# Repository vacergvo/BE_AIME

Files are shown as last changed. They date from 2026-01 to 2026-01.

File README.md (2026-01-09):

# Smart Device Project: Nanoparticle Gas Sensor & IoT Shield
**UF "Smart Devices" – PTP Innovative Smart System (ISS)**

## 1. Project Overview
This project is part of the **5ISS program at INSA Toulouse**. It focuses on the development of a **nanoparticle-based gas sensing system**, designed and characterized at **AIME**, the INSA Toulouse laboratory.

The project covers the full development cycle, from sensor fabrication to data visualization. A custom **PCB** was designed, and **ESP32 firmware** was developed to exploit the gas sensor measurements and transmit the data wirelessly. The collected data is then processed and displayed on a **web-based interface**.

The system relies on **LoRa communication** for long-range data transmission and integrates both hardware and software components.

The development chain consists of :

- Hardware design (analog signal amplified through a 2-stage transimpedance amplifier tested with LTSpice and PCB design with Kicad),

- Embedded software development using Arduino,

- LoRa wireless communication,

- Data processing and visualization using Node-RED,

- Mobile application development using MIT App Inventor.

## 2. The Measurement Chain
### Nanoparticle Gas Sensor (AIME)
Developed during a training period at AIME, this sensor utilizes:
* **Synthesis**: Nanoparticles produced and deposited by dielectrophoresis.
* **Active Zone**: A sensitive layer of $WO_3$ nanoparticles integrated on aluminum interdigitated combs.
* **Target Gases**: High sensitivity to Ethanol and Ammonium.
* **Control**: Features an internal poly-silicon heating resistor and an aluminum temperature sensor.

### Analog Interface Circuit
The sensor is interfaced via a transimpedance circuit designed to measure its resistance.
* **Amplification**: Utilizes an LTC1050 precision chopper amplifier.
* **Filtering**: A low-pass filter is implemented to extract useful signals before the ADC stage.
* **Simulation**: The circuit was validated using LTSpice IV.
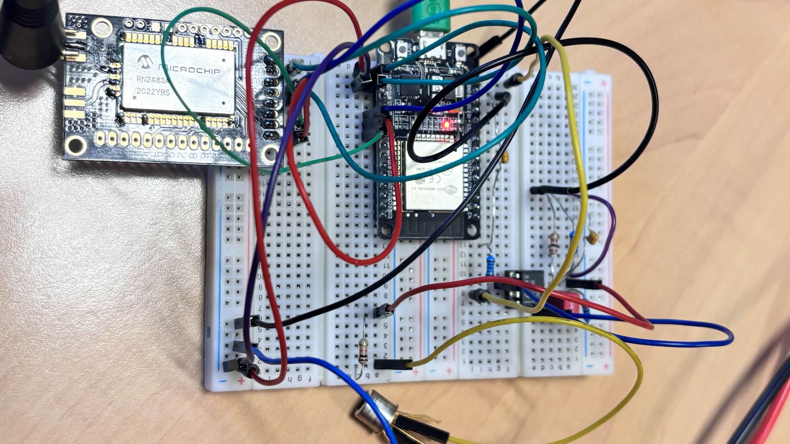
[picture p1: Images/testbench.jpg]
Hardware test

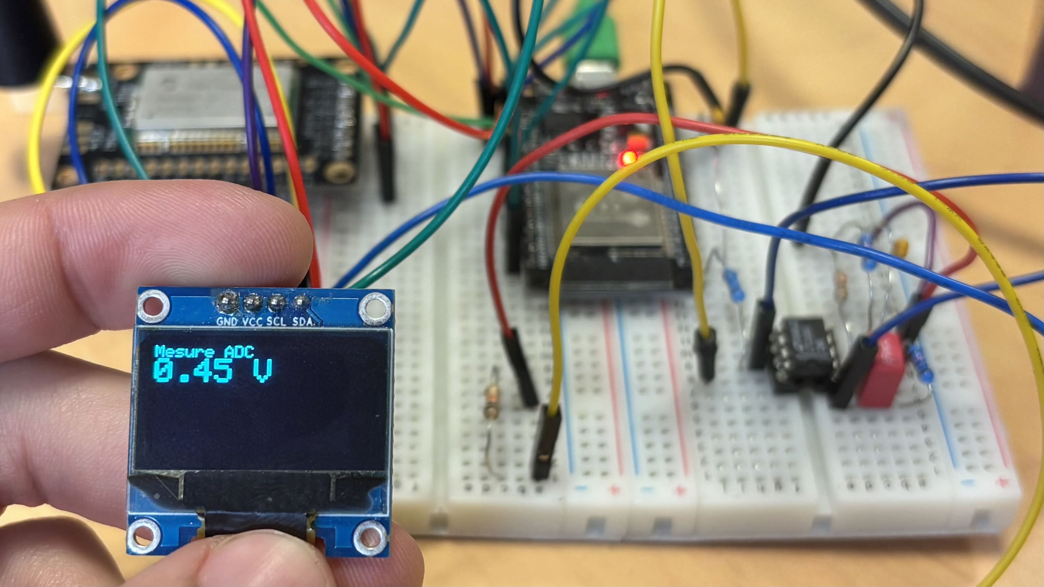
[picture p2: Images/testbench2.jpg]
Hardware test

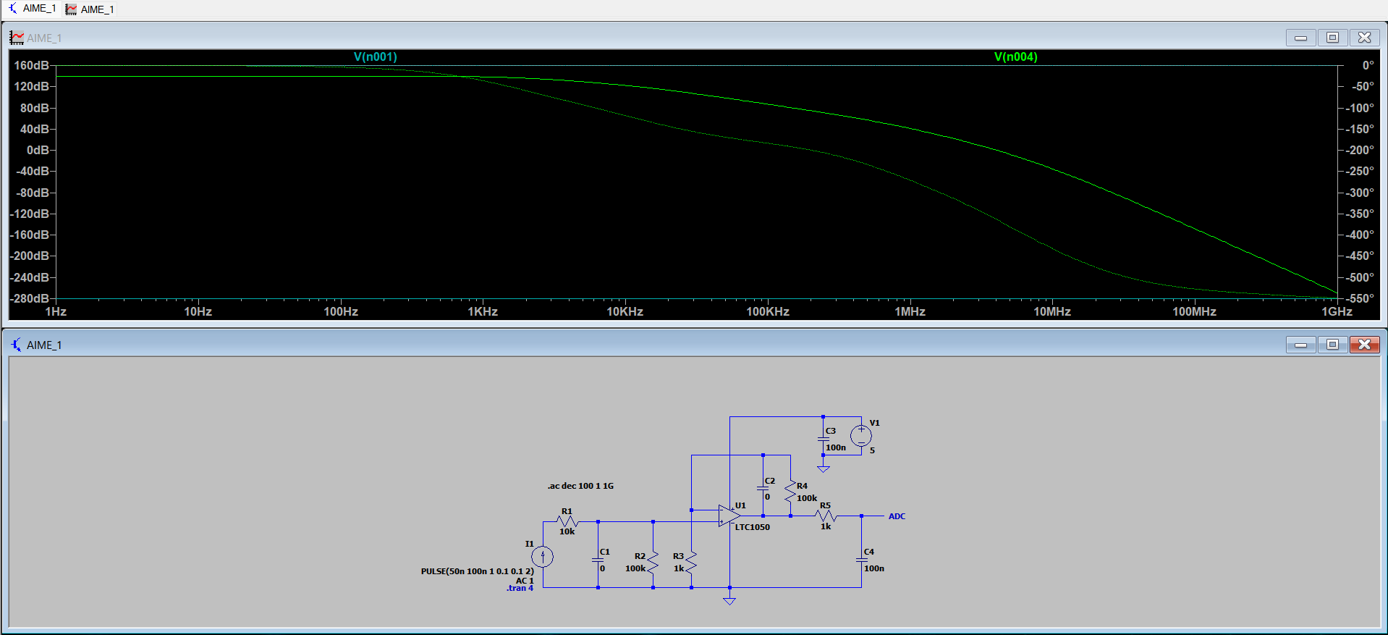
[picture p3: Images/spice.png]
LTSpice Simulation


---

## 3. Hardware Design (KiCad)
The PCB shield was designed following specific technical constraints to ensure compatibility with an Arduino UNO.

### Design Constraints:
* **Track Width**: 0.5 mm minimum.
* **Track Isolation**: 0.5 mm minimum.
* **Drill Sizes**: 1mm for headers/connectors; 0.8mm for passive components.

### Schematic & Routing
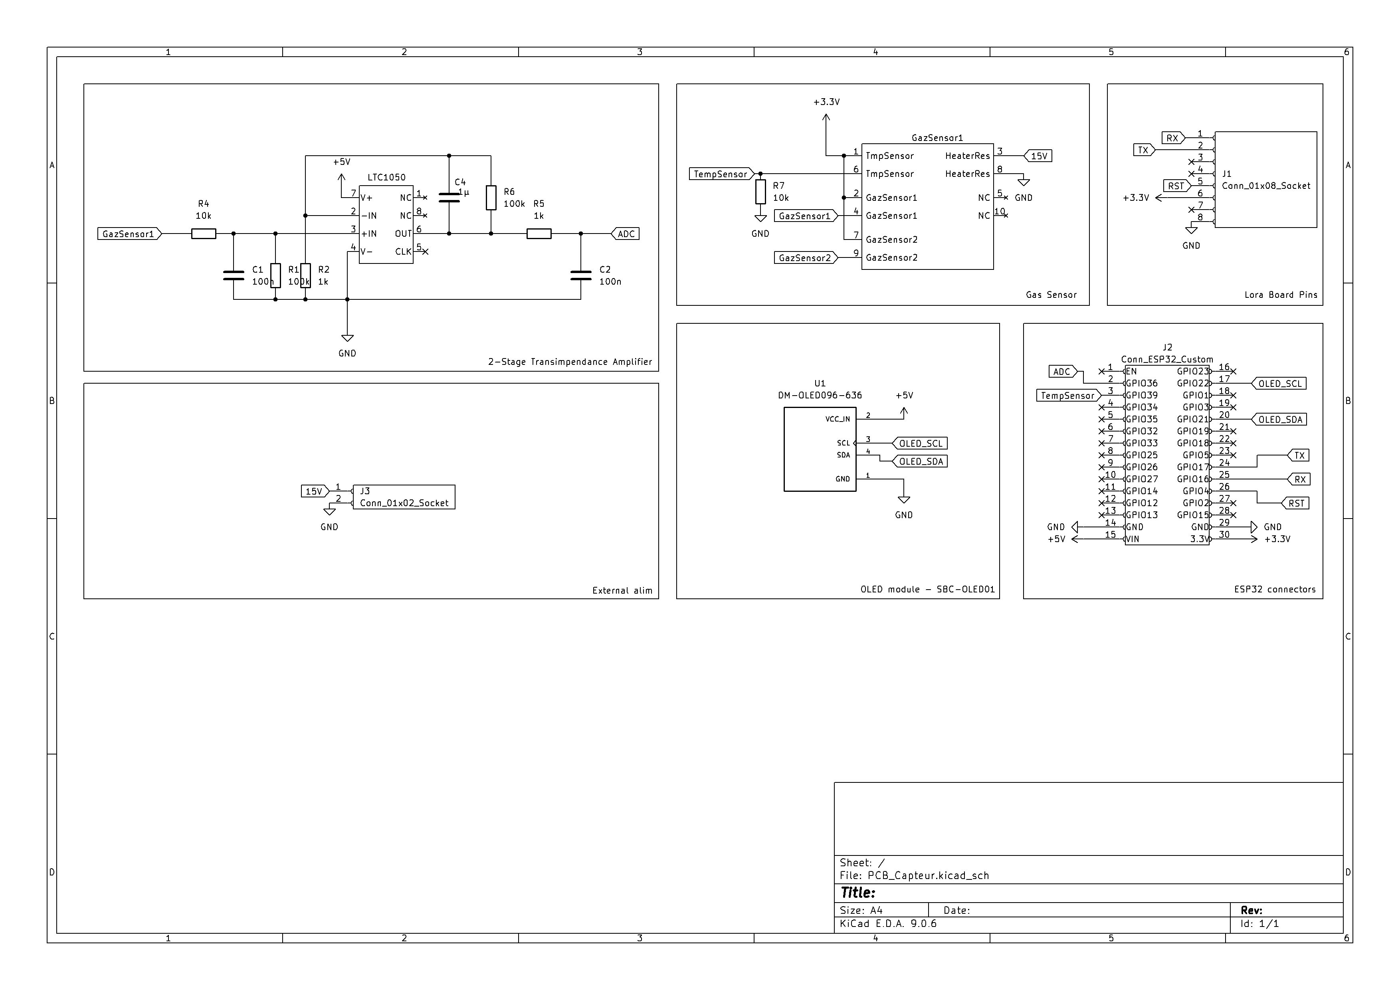
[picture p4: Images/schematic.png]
Schematic

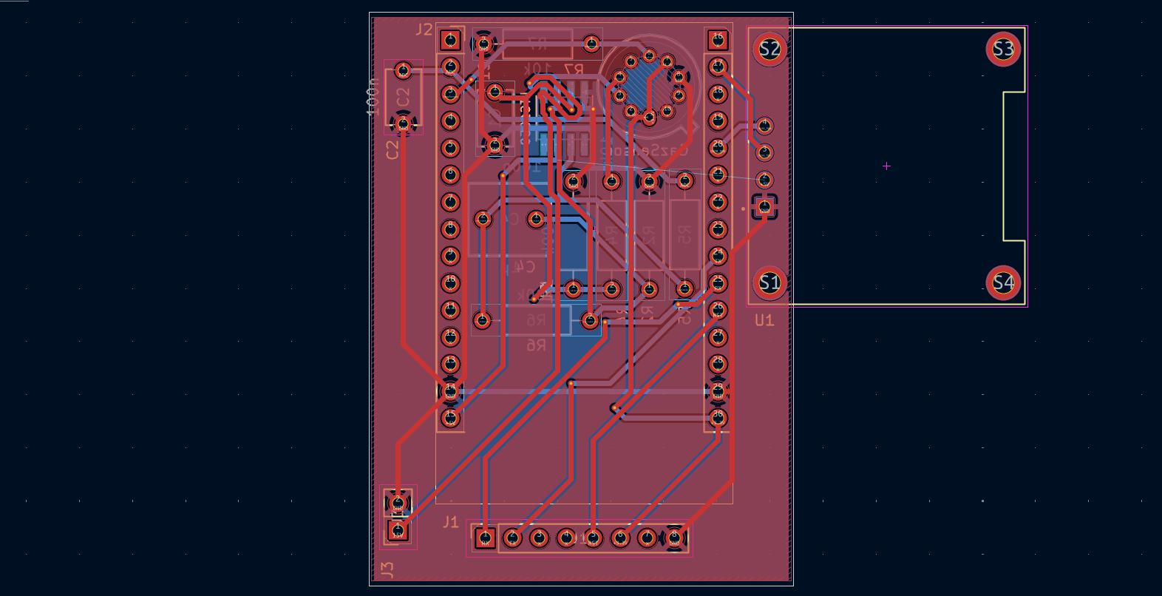
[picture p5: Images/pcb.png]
PCB Layout


### 3D Model
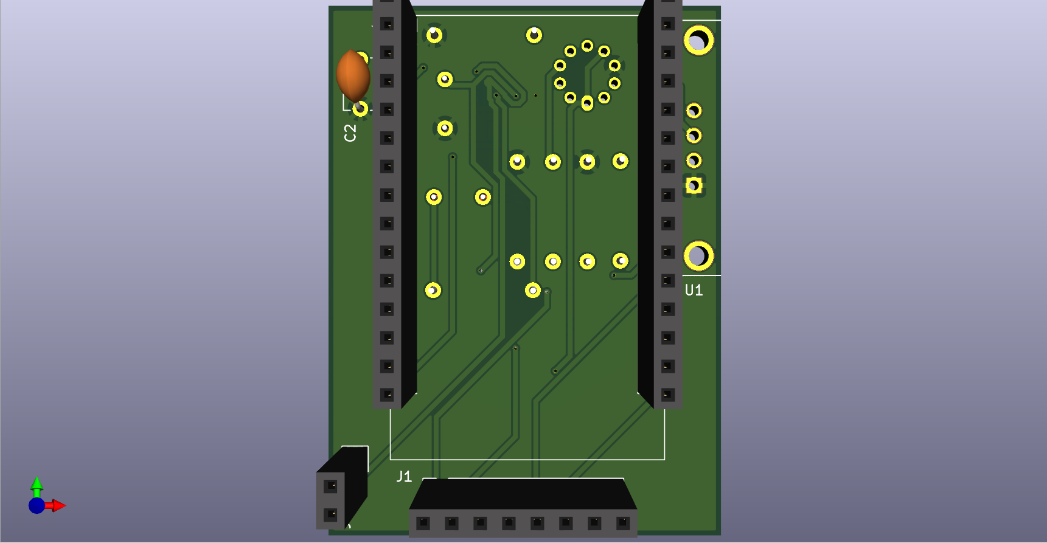
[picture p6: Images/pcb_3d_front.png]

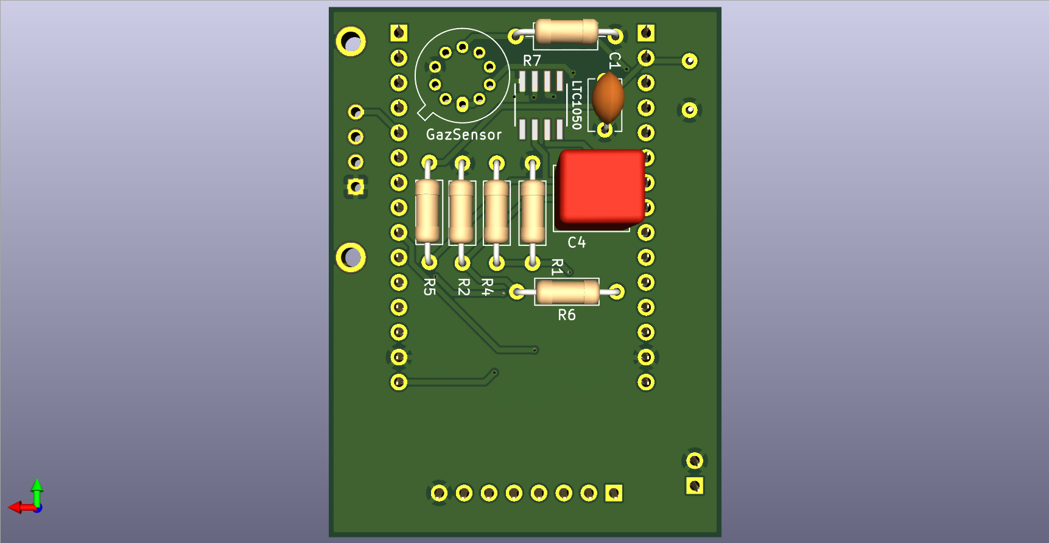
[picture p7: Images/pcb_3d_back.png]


---

## 4. Implementation & Software
* **Microcontroller**: Programmed for Arduino UNO / ESP32 platforms.
* **Connectivity**: Configured to send data over the The Things Network (TTN) via LoRa.
* **Version Control**: Developed collaboratively using Git and GitHub.
* **Interface**: NodeRed Application.

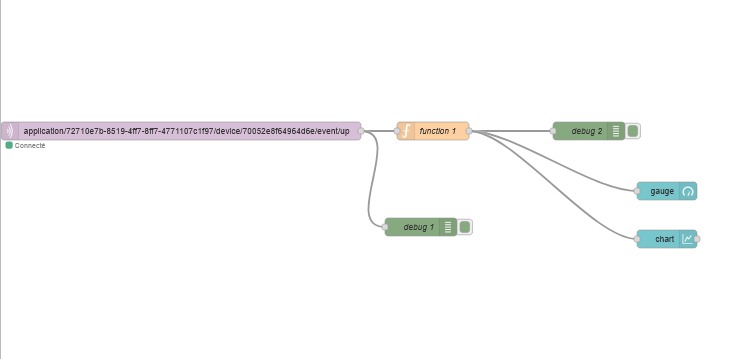
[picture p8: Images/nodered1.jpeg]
NodeRed

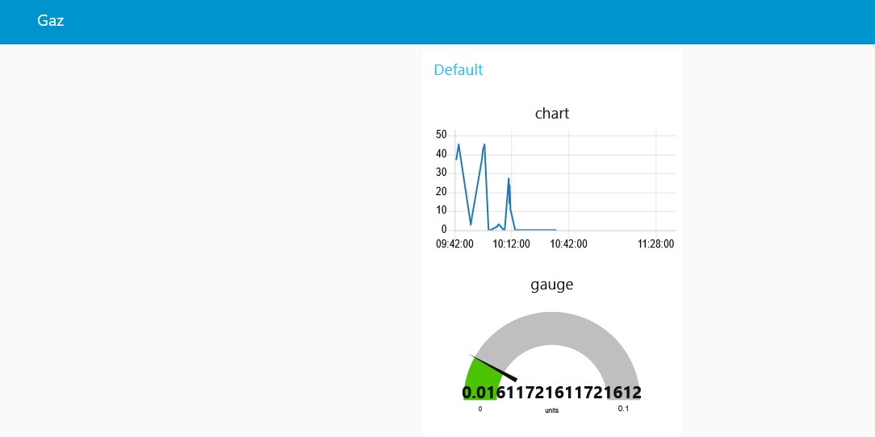
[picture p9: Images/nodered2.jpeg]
NodeRed


## 5. Repository Structure
* `/PCB_Capteur`: Schematic and Layout design files.
* `/Software`: Arduino/ESP32 source code for data acquisition.
* `/Spice`: Simulation files for the analog interface.
* `/Images`: Screenshots and documentation assets.

## 6. Authors & Credits
* **Student**: Tom Lassalle, Sandra Benjaoui, Louis Rousset
* **Supervisors**: J. Grisolia, A. Biganzoli, C. Crouzet, B. Mestre.
* **Partners**: AIME Toulouse (Atelier Interuniversitaire de Micro-nano Électronique).

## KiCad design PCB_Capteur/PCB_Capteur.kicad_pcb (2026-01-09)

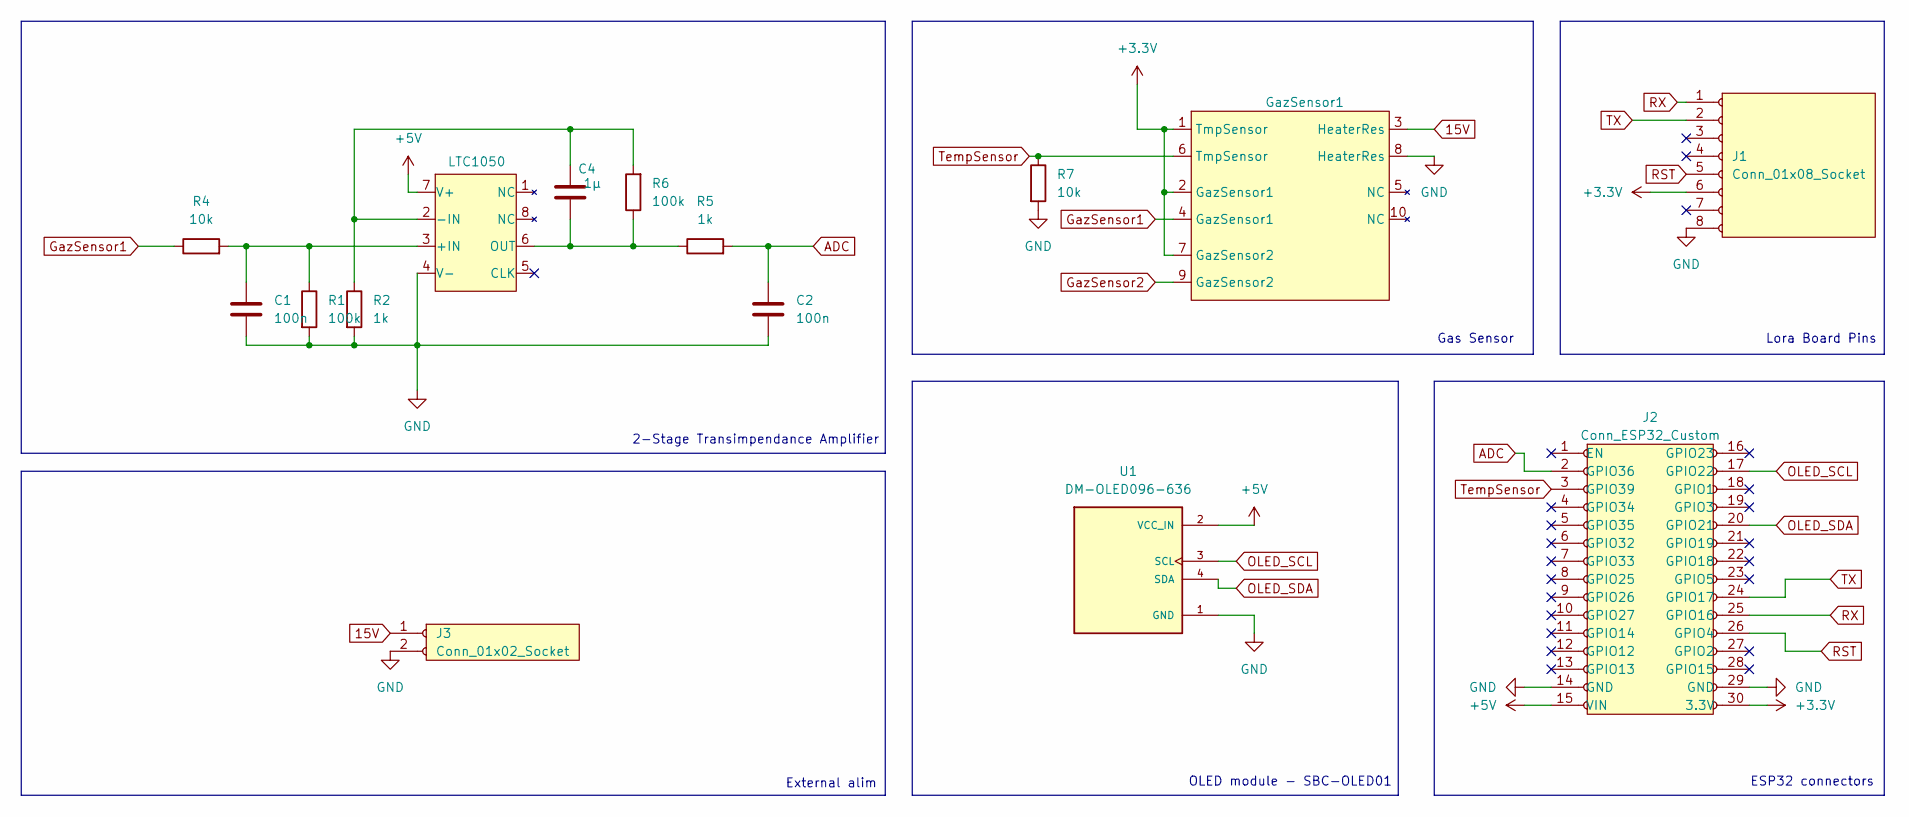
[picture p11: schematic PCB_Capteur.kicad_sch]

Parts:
C1, C2: 100n; C_Disc_D5.1mm_W3.2mm_P5.00mm
C4: 1µ; C_Rect_L7.5mm_W6.5mm_P5.00mm
GazSensor1: TO-5-10_Window
J1: Conn_01x08_Socket; PinSocket_1x08_P2.54mm_Vertical
J2: Conn_ESP32_Custom; Custom
J3: Conn_01x02_Socket; PinSocket_1x02_P2.54mm_Vertical
LTC1050: SO-8_S
R1, R6: 100k; R_Axial_DIN0207_L6.3mm_D2.5mm_P10.16mm_Horizontal
R2, R5: 1k; R_Axial_DIN0207_L6.3mm_D2.5mm_P10.16mm_Horizontal
R4, R7: 10k; R_Axial_DIN0207_L6.3mm_D2.5mm_P10.16mm_Horizontal
U1: DM-OLED096-636; MODULE_DM-OLED096-636; PARTREV 2018-09-10

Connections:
15V: GazSensor1.3 (HeaterRes), J3.1; also elsewhere on the board
+3.3V: GazSensor1.1 (TmpSensor), GazSensor1.2 (GazSensor1), GazSensor1.7 (GazSensor2), J1.6, J2.30 (3.3V); also elsewhere on the board
+5V: J2.15 (VIN), LTC1050.7 (V+), U1.2 (VCC_IN)
ADC: C2.1, J2.2 (GPIO36), R5.2
GND: C1.2, C2.2, GazSensor1.8 (HeaterRes), J1.8, J2.14 (GND), J2.29 (GND), J3.2, LTC1050.4 (V-), R1.2, R2.2, R7.2, U1.1 (GND); also elsewhere on the board
GazSensor1: GazSensor1.4 (GazSensor1), R4.1; also elsewhere on the board
unnamed: C1.1, LTC1050.3 (+IN), R1.1, R4.2
unnamed: C4.1, LTC1050.2 (-IN), R2.1, R6.2
unnamed: C4.2, LTC1050.6 (OUT), R5.1, R6.1
OLED_SCL: J2.17 (GPIO22), U1.3 (SCL)
OLED_SDA: J2.20 (GPIO21), U1.4 (SDA)
RST: J1.5, J2.26 (GPIO4)
RX: J1.1, J2.25 (GPIO16)
TX: J1.2, J2.24 (GPIO17)
TempSensor: GazSensor1.6 (TmpSensor), J2.3 (GPIO39), R7.1; also elsewhere on the board

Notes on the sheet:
External alim
OLED module - SBC-OLED01
Gas Sensor
2-Stage Transimpendance Amplifier
Lora Board Pins
ESP32 connectors

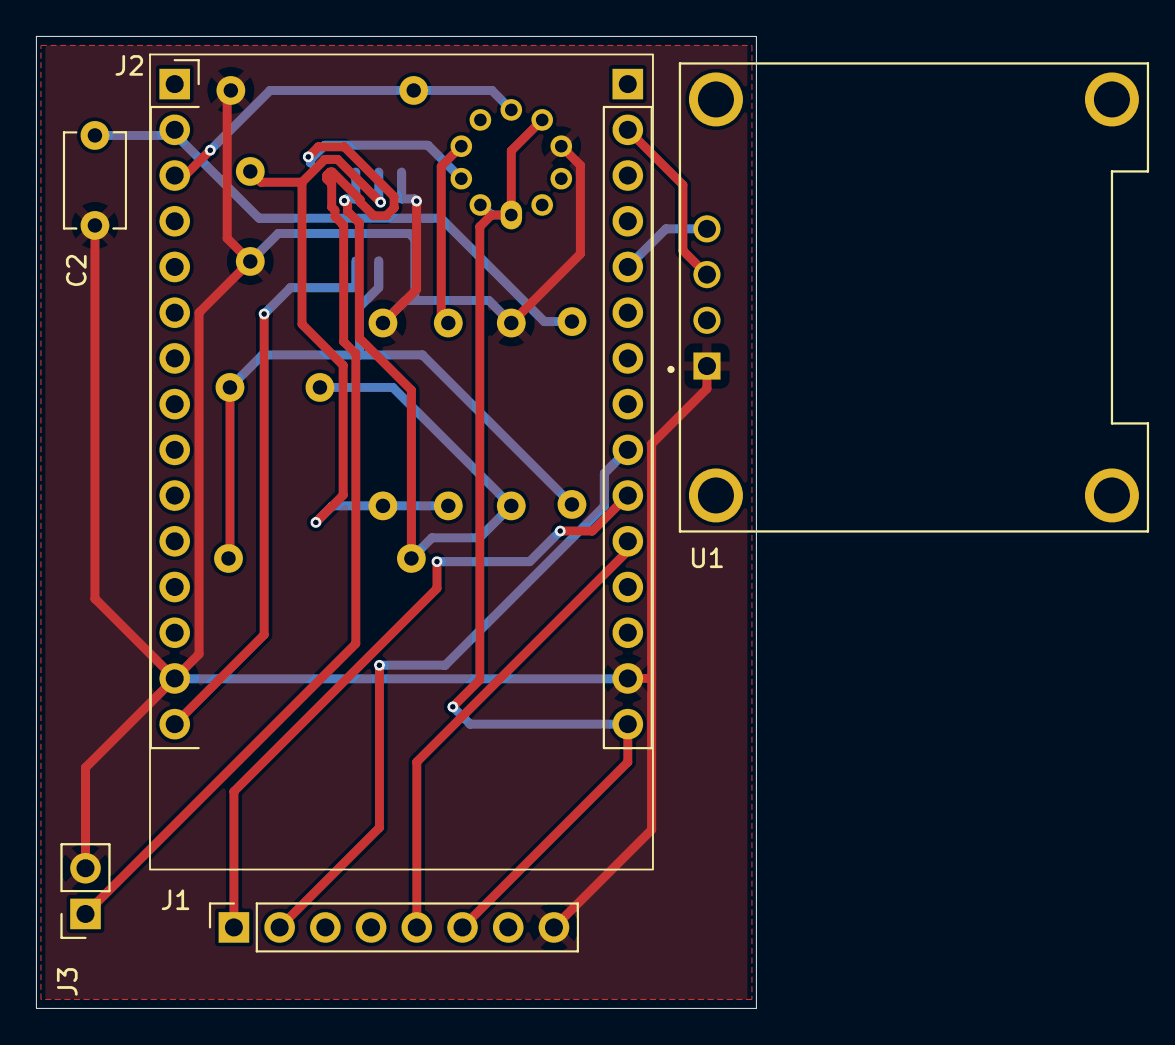
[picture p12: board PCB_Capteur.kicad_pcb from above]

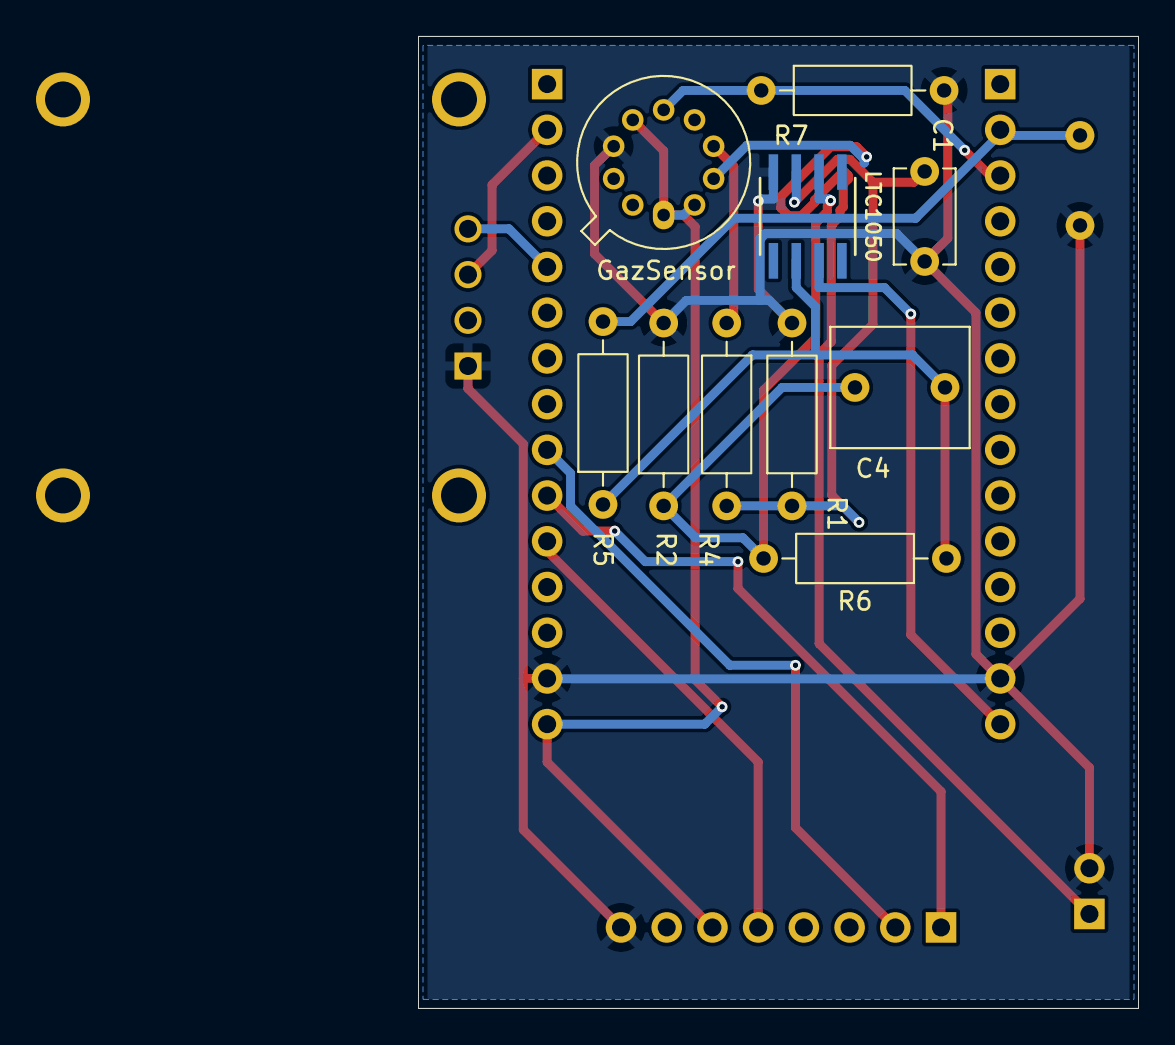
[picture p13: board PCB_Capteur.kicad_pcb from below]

Board: 2 copper layers, 40.0 x 54.0 mm, 15 parts (10 on the bottom side), 15 nets.

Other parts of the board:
GazSensor: TO-5-10_Window

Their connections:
15V: GazSensor.3 (HeaterRes); also elsewhere on the board
+3.3V: GazSensor.1 (TmpSensor), GazSensor.2 (GazSensor1), GazSensor.7 (GazSensor2); also elsewhere on the board
GND: GazSensor.8 (HeaterRes); also elsewhere on the board
GazSensor1: GazSensor.4 (GazSensor1); also elsewhere on the board
TempSensor: GazSensor.6 (TmpSensor); also elsewhere on the board

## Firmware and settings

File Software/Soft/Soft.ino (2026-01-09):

#include "BluetoothSerial.h"

#include <Wire.h>
#include <Adafruit_GFX.h>
#include <Adafruit_SSD1306.h>

/* ===================== CONFIGURATION ===================== */

// ---- LoRa RN2483 ----
#define RN_RESET 4
HardwareSerial lora(2);
unsigned long lastLoraSend = 0;
const unsigned long LORA_INTERVAL = 10000; // 10 s

// ---- Bluetooth ----
BluetoothSerial SerialBT;

// ---- ADC ----
#define ADC_PIN 36
unsigned long lastAdcRead = 0;
const unsigned long ADC_INTERVAL = 2000; //2s
int lastAdcValue = 0;

// ---- Ecran ----
#define SCREEN_WIDTH 128
#define SCREEN_HEIGHT 64
#define OLED_RESET -1
#define OLED_ADDR 0x3C

Adafruit_SSD1306 display(SCREEN_WIDTH, SCREEN_HEIGHT, &Wire, OLED_RESET);

// ---- Bl ----
bool screenEnabled = true;

/* ===================== FONCTIONS ===================== */

void sendLoraCommand(String cmd, int delayMs = 1000) {
  lora.println(cmd);
  delay(delayMs);
  while (lora.available()) {
    Serial.write(lora.read());
  }
  Serial.println();
}

void updateScreenPower() {
  if (screenEnabled) {
    display.ssd1306_command(SSD1306_DISPLAYON);
    display.clearDisplay();
    display.setTextSize(1);
    display.setTextColor(SSD1306_WHITE);
    display.setCursor(0, 0);
    display.println("Ecran ALLUME");
    display.display();
  } else {
    display.clearDisplay();
    display.display();
    display.ssd1306_command(SSD1306_DISPLAYOFF);
  }
}

void initDisplay() {
  if (!display.begin(SSD1306_SWITCHCAPVCC, OLED_ADDR)) {
    Serial.println("SSD1306 non détecté");
    while (true);
  }

  updateScreenPower();
}


void initLora() {
  lora.begin(57600, SERIAL_8N1, 16, 17);

  pinMode(RN_RESET, OUTPUT);
  digitalWrite(RN_RESET, LOW);
  delay(200);
  digitalWrite(RN_RESET, HIGH);
  delay(2000);

  sendLoraCommand("sys reset");
  sendLoraCommand("sys get ver");

  sendLoraCommand("mac set deveui 70052e8f64964d6e");
  sendLoraCommand("mac set appeui 30e09b3545acb1ce");
  sendLoraCommand("mac set appkey 19011e234a8bf6c30854f0447b724c4d");

  sendLoraCommand("mac set pwridx 5");
  sendLoraCommand("mac join otaa");
  delay(5000);
}

void initADC() {
  analogReadResolution(12);
  analogSetPinAttenuation(ADC_PIN, ADC_11db);
}

void readADC() {
  lastAdcValue = analogRead(ADC_PIN);
  float tension = lastAdcValue * 3.3 / 4095.0;

  Serial.print("ADC = ");
  Serial.print(lastAdcValue);
  Serial.print(" | Tension = ");
  Serial.print(tension);
  Serial.println(" V");

  SerialBT.println(tension);

  if (screenEnabled){
    display.clearDisplay();
    display.setCursor(0, 0);
    display.setTextSize(1);
    display.println("Mesure ADC");

    display.setTextSize(2);
    display.print(tension, 2);
    display.println(" V");

    display.display();
  }
}


void sendLoraPayload() {
  char payload[5]; // 2 octets = 4 caractères hex
  sprintf(payload, "%04X", lastAdcValue);

  Serial.println(payload);

  String cmd = "mac tx uncnf 1 ";
  cmd += payload;

  sendLoraCommand(cmd);
}

void handleBluetooth() {
  if (SerialBT.available()) {
    int n = SerialBT.read();
    Serial.print("Bluetooth reçu : ");
    Serial.println(n);

    if (n == 1) {
      screenEnabled = !screenEnabled; 
      updateScreenPower();
      SerialBT.println(screenEnabled ? "SCREEN_ON" : "SCREEN_OFF");
    }
  }
}


/* ===================== SETUP ===================== */

void setup() {
  Serial.begin(115200);
  delay(1000);
  Serial.println("ESP32 démarrage...");

  SerialBT.begin("ESP32_LED");
  Serial.println("Bluetooth initialisé");

  initADC();

  Wire.begin(21, 22);   // SDA, SCL
  initDisplay();

  initLora();

  Serial.println("Système prêt !");
}

/* ===================== LOOP ===================== */

void loop() {
  unsigned long now = millis();

  handleBluetooth();

  if (now - lastAdcRead >= ADC_INTERVAL) {
    lastAdcRead = now;
    readADC();
  }

  if (now - lastLoraSend >= LORA_INTERVAL) {
    lastLoraSend = now;
    sendLoraPayload();
  }
}

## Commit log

2025-12-08 Kicad amplification stage
    [PCB_AIME.kicad_pcb, PCB_AIME.kicad_sch]
2026-01-06 PCB Update + Amplification stage simulation
    [PCB_AIME.kicad_pcb, PCB_AIME.kicad_sch, PCB_Capteur.kicad_pcb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]
2026-01-06 PCB Improvements
    [PCB_Capteur.kicad_pcb]
2026-01-06 PCB Optimizations
    [PCB_Capteur.kicad_pcb]
2026-01-09 Adding Images for the readme
    [PCB_Capteur.kicad_pcb, PCB_Capteur.kicad_sch]
